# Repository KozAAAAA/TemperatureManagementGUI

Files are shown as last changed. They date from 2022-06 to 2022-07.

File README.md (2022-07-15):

# Temperature Manangement GUI

<p align="center">
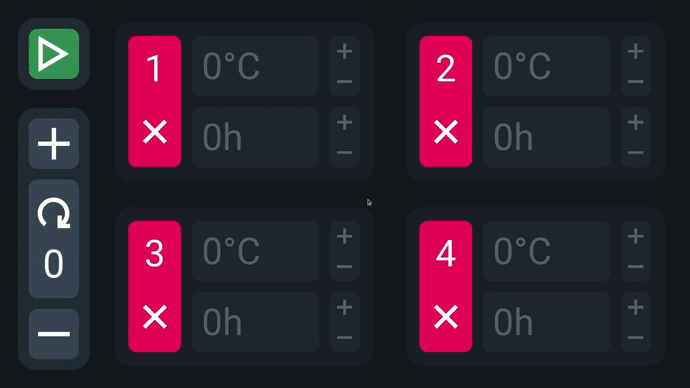
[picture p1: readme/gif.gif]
  
</p>

<p align="center">
  The Raspberry Pi GUI that lets you control the temperature of a chamber.
</p>

<p align="center">
  
  
   
</p>

## Key feautures
* The **temperature** values are settable (GUI).
* The **time** periods are settable (GUI).
* The number of **repeats** is settable (GUI).
* The **hysteresis** value is customizable (settings.h).
* **Relay** & **Fan** RPi **pins** are customizable (settings.h).
* Compiles on **arm** as well as **x86** thanks to the use of **preprocessor** & **qmake**.
* Puts controlled **GPIO** pins to **LOW** if program is turned off.
* Displays **error messages** whenever **python script** or **txt file** is unavailable.
* Checks whether the read **temperature** is valid.
* Hardware uses **PT100** & **custom PCB** to read the temperature via the **SPI protocol**.
* Temperature is **controlled** via the **relay**.
* All of the important data displays if the start button is clicked.
* made with **C++17**, **QML** & **Python**
## User Flow Diagram

<p align="center">
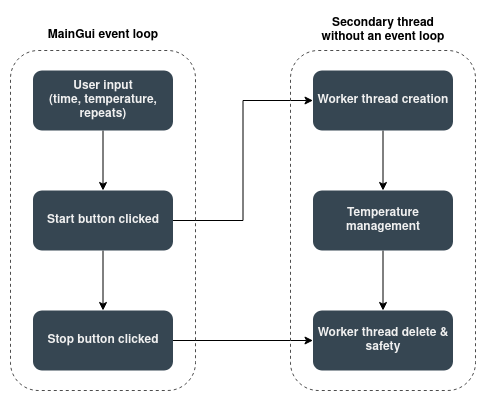
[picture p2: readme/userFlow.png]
  
</p>

## Hardware
The circuit shown below is the Raspberry Pi hat that makes **temperature reading** & **relay control** possible.
<p align=“center”>
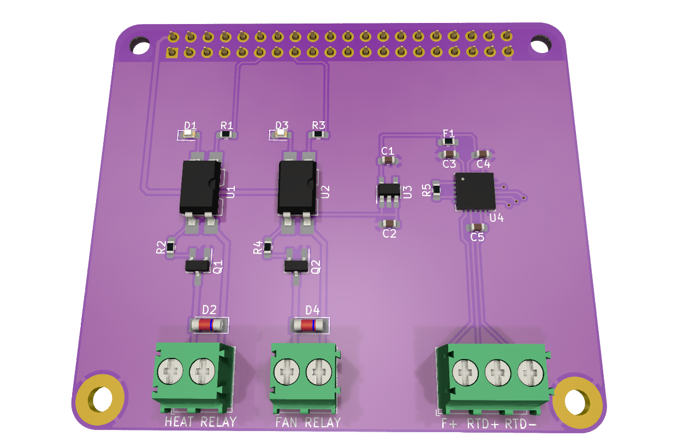
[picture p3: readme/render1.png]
  
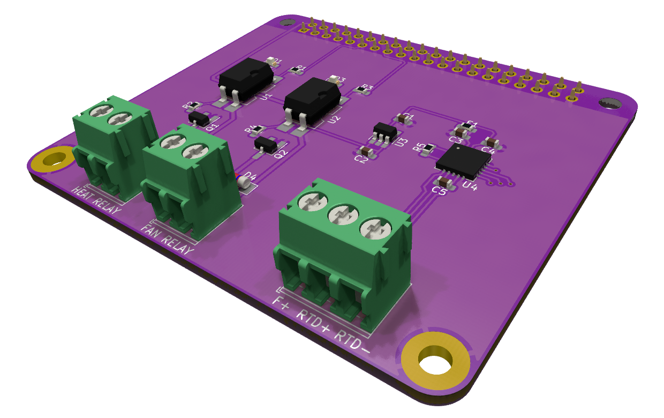
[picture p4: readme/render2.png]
  
  “Sublime’s
</p>

## Installation

Raspbian installation:

```bash
  coming soon...
```

## License

All code is released under the [MIT](https://choosealicense.com/licenses/mit/) License.

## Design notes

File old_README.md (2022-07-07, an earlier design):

# Temperature Management GUI



full KMS - działa rozmiar okna, musi być podłączony monitor, nie wypierdala błędu libGLES
no OpenGL - działa rozmiar okna, nie musi być monitora, wypierdala błąd libGLES
fake KMS - pizda
przesył danych do rpi:
rsync -zaP ~/Desktop/TemperatureMenagmentGUI/TemperatureMenagmentGUI pi@192.168.148.219:~/Desktop/

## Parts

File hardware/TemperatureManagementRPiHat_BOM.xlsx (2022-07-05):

Item | Name | Qty | Reference | Price | Part page
1 | Capacitor 0.1uF | 3 | C1, C3, C5 | 1.33 zł | https://www.mouser.pl/ProductDetail/Samsung-Electro-Mechanics/CL10B104JB8NNNC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
2 | Capacitor 10uF | 2 | C2, C4 | 1.68 zł | https://www.mouser.pl/ProductDetail/Samsung-Electro-Mechanics/CL10A106MP8NNND
3 | Red LED | 2 | D1, D3 | 2.30 zł | https://www.mouser.pl/ProductDetail/Lite-On/LTST-C191KRKT?qs=sGAEpiMZZMuCm2JlHBGefiI6XTgwWTjBqIuscz6Upzw%3D
4 | Diode LL4148 | 2 | D2, D4 | 1.15 zł | https://www.mouser.pl/ProductDetail/onsemi-Fairchild/LL4148?qs=sGAEpiMZZMtbRapU8LlZD9kBCaIQZVuxfJdpmPGhl1k%3D
5 | Fuse 50mA | 1 | F1 | 3.53 zł | https://www.mouser.pl/ProductDetail/Kyocera-AVX/F0603G0R05FNTR?qs=JtEK8acvKOPEA8BapUZ1nQ%3D%3D
6 | Screw Terminal x2 2.54mm | 2 | J1 J2 | 4.86 zł | https://www.mouser.pl/ProductDetail/Phoenix-Contact/1984617?qs=ATjOrvm3mOhUrGlJQoUcpQ%3D%3D
7 | Screw Terminal x3 2.54mm | 1 | J3 | 3.53 zł | https://www.mouser.pl/ProductDetail/Phoenix-Contact/1984620?qs=qPbxTIUfeZanCGLWbKOtjg%3D%3D
8 | Pin Socket 2x20 2.54mm | 1 | J4 | 8.46 zł | https://www.mouser.pl/ProductDetail/Wurth-Elektronik/61304021821?qs=bZr6mbWTK5mzEvTTGhcEyQ%3D%3D
9 | Transistor NPN S8050 | 2 | Q1, Q2 | 1.86 zł | https://www.mouser.pl/ProductDetail/Micro-Commercial-Components-MCC/MMSS8050-L-TP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
10 | Resistor 180Ω | 2 | R1, R3 | 0.88 zł | https://www.mouser.pl/ProductDetail/Panasonic/ERJ-3GEYJ181V?qs=sGAEpiMZZMvdGkrng054t8AJgcdMkx7xzUQtm7qOYxE%3D
11 | Resistor 510Ω | 2 | R2, R4 | 0.88 zł | https://www.mouser.pl/ProductDetail/Panasonic/ERJ-3GEYJ511V?qs=sGAEpiMZZMvdGkrng054t8ugkoYZivkgIzDDCM6DO7s%3D
12 | Resistor 430Ω, 0.1% | 1 | R5 | 1.55 zł | https://www.mouser.pl/ProductDetail/Panasonic/ERA-3AEB431V
13 | Optocoupler FOD817 | 2 | U1, U2 | 5.12 zł | https://www.mouser.pl/ProductDetail/onsemi-Fairchild/FOD817B3SD?qs=32VJUWvZ7XaPAttVzV2Zlg%3D%3D
14 | Voltage regulator MIC5245-3.3 | 1 | U3 | 3.05 zł | https://www.mouser.pl/ProductDetail/Microchip-Technology/MIC5245-3.3YM5-TR?qs=U6T8BxXiZAXkopuvjIDr5w%3D%3D
15 | IC MAX31865 | 1 | U4 | 33.15 zł | https://www.mouser.pl/ProductDetail/Maxim-Integrated/MAX31865ATP%2bT?qs=mIV%2FTjyUFhl0J5LgcLJnSg%3D%3D
 |  | Suma: |  | 73.33 zł
 |  | Suma bez U1/2/4 |  | 35.06 zł

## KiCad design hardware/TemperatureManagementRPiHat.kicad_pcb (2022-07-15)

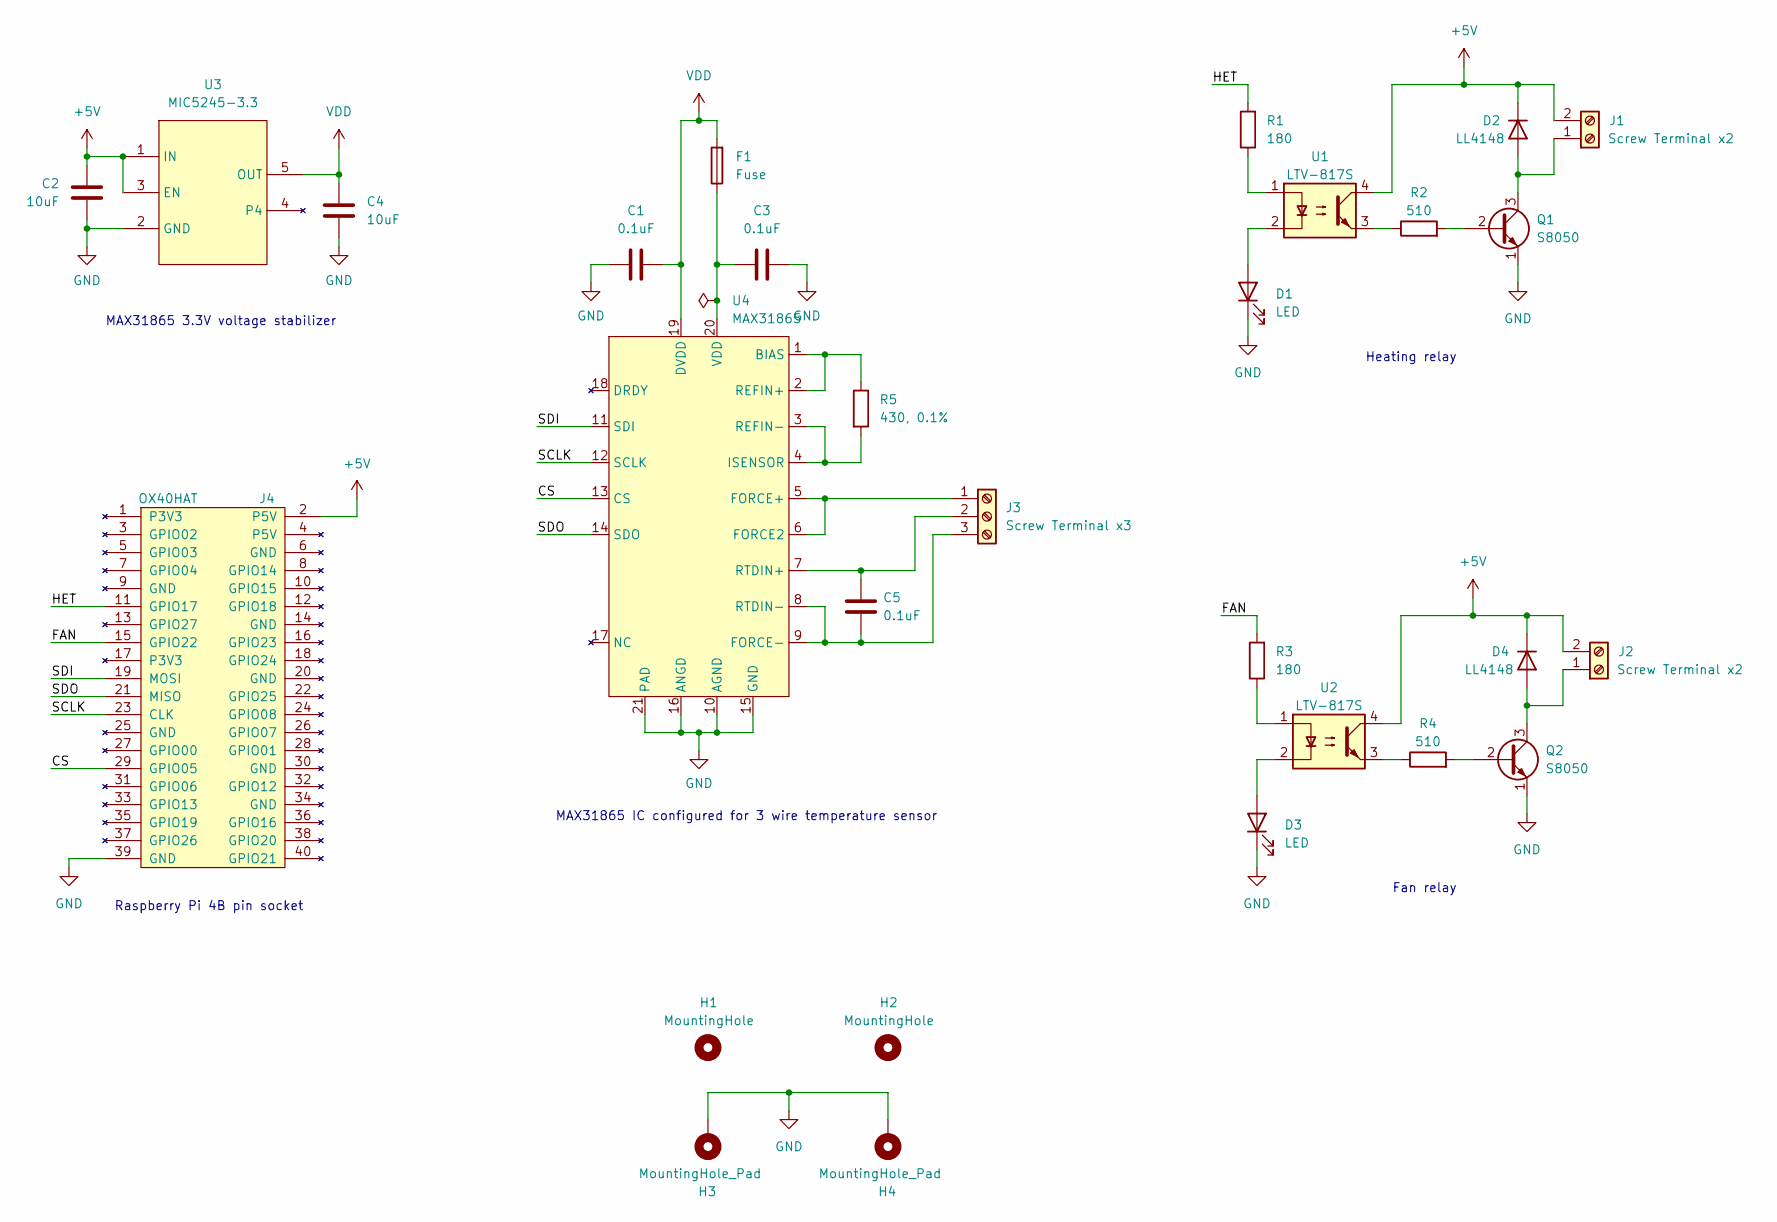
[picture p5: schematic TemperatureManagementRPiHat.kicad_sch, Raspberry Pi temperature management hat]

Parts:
C1, C3, C5: 0.1uF; C_0603_1608Metric_Pad1.08x0.95mm_HandSolder
C2, C4: 10uF; C_0603_1608Metric_Pad1.08x0.95mm_HandSolder
D1, D3: LED; LED_0603_1608Metric_Pad1.05x0.95mm_HandSolder
D2, D4: LL4148; D_MiniMELF
F1: Fuse; Fuse_0603_1608Metric_Pad1.05x0.95mm_HandSolder
H1, H2: MountingHole; MountingHole_3mm
H3, H4: MountingHole_Pad; MountingHole_3mm_Pad
J1, J2: Screw Terminal x2; TerminalBlock_Phoenix_PT-1,5-2-3.5-H_1x02_P3.50mm_Horizontal
J3: Screw Terminal x3; TerminalBlock_Phoenix_PT-1,5-3-3.5-H_1x03_P3.50mm_Horizontal
J4: OX40HAT; PinSocket_2x20_P2.54mm_Vertical
Q1, Q2: S8050; SOT-23_Handsoldering
R1, R3: 180; R_0603_1608Metric_Pad0.98x0.95mm_HandSolder
R2, R4: 510; R_0603_1608Metric_Pad0.98x0.95mm_HandSolder
R5: 430, 0.1%; R_0603_1608Metric_Pad0.98x0.95mm_HandSolder
U1, U2: LTV-817S; SMDIP-4_W9.53mm
U3: MIC5245-3.3; SOT-23-5_HandSoldering
U4: MAX31865; TQFN-20-1EP_5x5mm_P0.65mm_EP3.1x3.1mm

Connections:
+5V: C2.2, D2.1 (K), D4.1 (K), J1.2, J2.2, J4.2 (P5V), U1.4, U2.4, U3.1 (IN), U3.3 (EN)
/CS: J4.29 (GPIO05), U4.13 (CS)
/FAN: J4.15 (GPIO22), R3.2
/HET: J4.11 (GPIO17), R1.2
/SCLK: J4.23 (CLK), U4.12 (SCLK)
/SDI: J4.19 (MOSI), U4.11 (SDI)
/SDO: J4.21 (MISO), U4.14 (SDO)
GND: C1.2, C2.1, C3.1, C4.2, D1.1 (K), D3.1 (K), H3.1, H4.1, J4.39 (GND), Q1.1 (E), Q2.1 (E), U3.2 (GND), U4.10 (AGND), U4.15 (GND), U4.16 (ANGD), U4.21 (PAD)
unnamed: C3.2, F1.1, U4.20 (VDD)
unnamed: C5.1, J3.2, U4.7 (RTDIN+)
unnamed: C5.2, J3.3, U4.8 (RTDIN-), U4.9 (FORCE-)
unnamed: D1.2 (A), U1.2
unnamed: D2.2 (A), J1.1, Q1.3 (C)
unnamed: D3.2 (A), U2.2
unnamed: D4.2 (A), J2.1, Q2.3 (C)
unnamed: Q1.2 (B), R2.2
unnamed: Q2.2 (B), R4.2
unnamed: R1.1, U1.1
unnamed: R2.1, U1.3
unnamed: R3.1, U2.1
unnamed: R4.1, U2.3
unnamed: R5.1, U4.1 (BIAS), U4.2 (REFIN+)
unnamed: R5.2, U4.3 (REFIN-), U4.4 (ISENSOR)
unnamed: J3.1, U4.5 (FORCE+), U4.6 (FORCE2)
VDD: C1.1, C4.1, F1.2, U3.5 (OUT), U4.19 (DVDD)

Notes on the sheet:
MAX31865 3.3V voltage stabilizer
Raspberry Pi 4B pin socket
Heating relay
Fan relay
MAX31865 IC configured for 3 wire temperature sensor

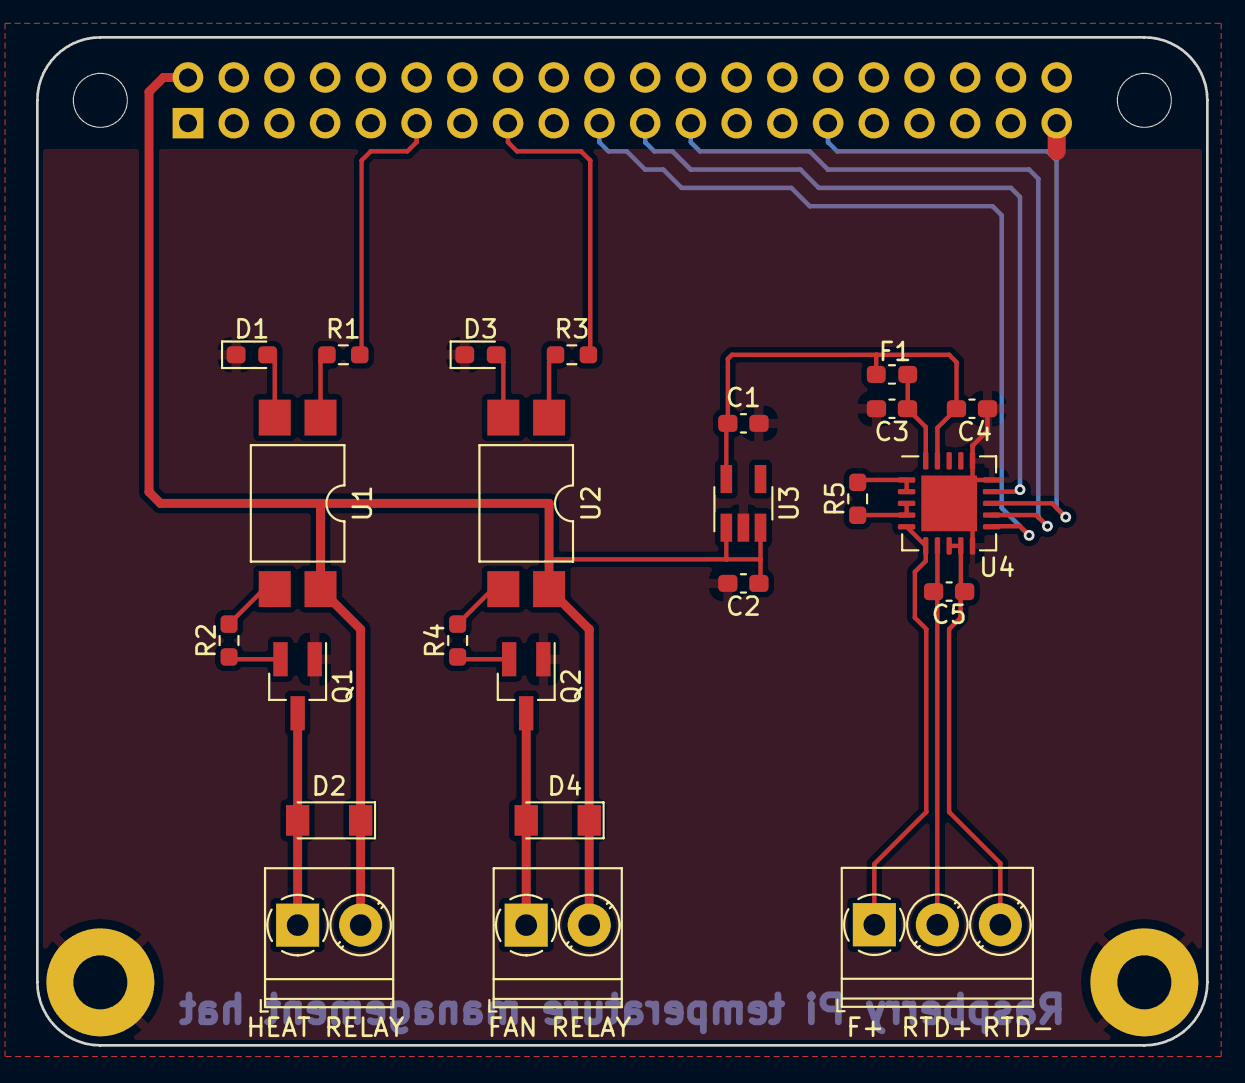
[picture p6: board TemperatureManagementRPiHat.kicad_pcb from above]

Board: 2 copper layers, 65.0 x 56.0 mm, 29 parts (1 on the bottom side), 25 nets.

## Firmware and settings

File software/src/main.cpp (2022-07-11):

#include <QGuiApplication>
#include <QQmlApplicationEngine>
#include <QQmlContext>

#include "maingui.h"



int main(int argc, char *argv[])
{
#if QT_VERSION < QT_VERSION_CHECK(6, 0, 0)
    QCoreApplication::setAttribute(Qt::AA_EnableHighDpiScaling);
#endif

#ifdef __arm__
    wiringPiSetup();
    pinMode(RELAY, OUTPUT);
    pinMode(FAN, OUTPUT);
    auto exitFunc = [](){digitalWrite(RELAY,LOW);
                         digitalWrite(FAN,LOW);
                         qDebug()<< "SAFETY HANDLER: evoked";};
#else
    auto exitFunc = [](){qDebug() << "SAFETY HANDLER: evoked";};
#endif

    std::atexit(exitFunc);

    MainGui* _MainGui = new MainGui;

    QGuiApplication app(argc, argv);
    QQmlApplicationEngine engine;
    engine.rootContext()->setContextProperty("_cppBackend",_MainGui);

    engine.load(QUrl(QStringLiteral("qrc:/main.qml")));
    if (engine.rootObjects().isEmpty())
        return -1;

    int ret;
    try
    {
        ret = app.exec();
    }
    catch(...)
    {
        exitFunc();
        qCritical() << "ERROR: Main crashed";
        return EXIT_FAILURE;
    }

    return ret;



}

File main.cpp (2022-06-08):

#include <QGuiApplication>
#include <QQmlApplicationEngine>
#include <QQmlContext>
#include "loopclass.h"
#include "maingui.h"

#include <QFontDatabase>


int main(int argc, char *argv[])
{
#if QT_VERSION < QT_VERSION_CHECK(6, 0, 0)
    QCoreApplication::setAttribute(Qt::AA_EnableHighDpiScaling);
#endif

    MainGui* temperatureMenagment = new MainGui;

    QGuiApplication app(argc, argv);
    QQmlApplicationEngine engine;
    engine.rootContext()->setContextProperty("_cppBackend",temperatureMenagment);

    engine.load(QUrl(QStringLiteral("qrc:/main.qml")));
    if (engine.rootObjects().isEmpty())
        return -1;

    return app.exec();

}

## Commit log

2022-03-30 Upgraded the temperaturemenagment.cpp
2022-03-30 Completed a Qml to Cpp communication. Added a method to print the variables.
2022-04-27 Added the conditional methods and includes for the ARM specific only. Deleted all the unnecesary files. Altered the behaviour of START button.
2022-05-06 Threads are workinggit add .!
2022-05-10 Competed the START-STOP functionallity - clicking the STOP button kills the qThread along with the Worker
2022-05-10 Sending to and reciving data from the second thread works. There is a need to change all of the ints to qints
2022-05-17 Time, loop and block changing works. Time is displayed in hh::mm::ss format. Button changes to START when WORKER is deleted. Program won't start if the variable loopInput is equal to 0.
    [worker.cpp]
2022-05-20 Heating indication has been added. Program wont start when neither of timers is on.
2022-05-25 A working RaspberryPi version
2022-06-19 Error property has been added. Worker to MainGui error passing has to be added.
    [worker.cpp]
2022-06-21 Input Parameters Printing has been optimised.
2022-06-29 kicad .gitignore
2022-06-29 hardware push - krzychu
    [Raspberry Pi temperature management hat BOM.xlsx, Raspberry Pi temperature management hat.csv, Raspberry Pi temperature management hat.kicad_pcb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]
2022-06-29 A working arm & x86 version
2022-07-04 Bad temperature reading handling has been implemented
2022-07-04 PCB board V2
    [Raspberry Pi temperature management hat BOM.xlsx, Raspberry Pi temperature management hat.csv, Raspberry Pi temperature management hat.kicad_pcb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]
2022-07-05 final version of V2 board with gerber files
    [Raspberry Pi temperature management hat-B_Cu.gbl, Raspberry Pi temperature management hat-B_Mask.gbs, Raspberry Pi temperature management hat-B_Paste.gbp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]
2022-07-05 stencil gerber file added
    [Raspberry Pi temperature management hat BOM.xlsx, Raspberry Pi temperature management hat.kicad_pcb, Raspberry Pi temperature management hat.kicad_sch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]
2022-07-05 App shutdown is now handled by the std::atexit() function, wiringPi setup has been moved to main.cpp, catch for every exception has been added.
2022-07-07 some unimportant changes
    [Raspberry Pi temperature management hat-F_Paste.dxf]
2022-07-11 Exceptions are safer (no GUI action, just termination), garbage readTemp value fixed
    [main.cpp, worker.cpp]
2022-07-11 #2 Bug fix - impossible to spawn more than one worker
    [worker.cpp]
2022-07-11 Start/Stop button is unclickable until the transition ends
2022-07-13 Error messages without the use of try and catch (safer, as QT states so)
    [main.cpp, worker.cpp]
2022-07-13 Cleaner code, removed the resetOutput method, removed the unnecessary code
    [worker.cpp]
2022-07-15 added renders to readme
    [Raspberry Pi temperature management hat BOM.xlsx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]
